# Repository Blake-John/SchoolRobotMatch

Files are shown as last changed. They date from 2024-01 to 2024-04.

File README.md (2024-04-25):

# RobotMatch

该仓库用于存放华工机器人校内赛的各种 **代码，文件，资料** 等其中，主要分为

* `ComputerVisioin` 
* `Microccontroller` 
* `MechanicalStructure` 

三个板块，其中

* `ComputerVision` 用于存放视觉识别的相关代码，模型等
* `Microcontroller` 用于存放电控的相关代码，电路板设计等资料
* `MechanicalStructure` 用于存放小车的结构，模型等

> 详细更新信息请阅读 [CHANGELOG](CHANGELOG.md)

## 1. ComputerVisioin

### 1.0 Structure

```
.
├── Modules                        # 一些模块
├── MidTermAssessment              # 中期考核程序
├── debugging                      # 存放用于赛前赛时调试用的程序
└── VisionSolutions                # 比赛瞄准项目
```

### 1.1 Modules

存放这一些准备比赛时使用的模块，较为杂

### 1.2 MidTermAssessment

用于提交 **中期考核** ，代码效果展示见 [Video](./ComputerVision/MidTermAssessment/medias/1.mkv)

详情可见 [MidTermAssessment](./ComputerVision/MidTermAssessment/README.md) 以及 [What to do](./ComputerVision/MidTermAssessment/TODO.md)

### 1.3 debugging

关于该目录可见 [debugging](./ComputerVision/debugging/README.md) 以及 [what to do](./ComputerVision/debugging/TODO.md)

### 1.4 VisionSolutions

视觉方面的项目目录，存放了用于比赛瞄准的程序，可见 [VisionSolutions](./ComputerVision/VisionSolutions/README.md) 以及 [What to do](./ComputerVision/VisionSolutions/TODO.md)

## 2. MicroController

### 2.0 Structure

```
.
├── MajorControl_Source            # 比赛小车控制项目
├── PID速度环控制
├── RemoteController_nRF20L01      # 控制手柄
├── SerialControl                  # 串口通信代码
├── SerialMCU
└── SerialPWM
```

### 2.1 SerialControl

串口通信模块，实现在 Linux 系统下，通过 C++ 程序与 STM32 通信

### 2.2 SerialMCU

接受信息模块，将接受到的特定数据包在OLED上显示

### 2.3 SerialPWM

接受信息，并控制舵机旋转

### 2.4 RemoteController_nRF20L01

控制手柄的pcb项目

### 2.5 MajorControl_Source

电控的 PCB 板源文件， `ZET6` 主控板源代码， `C8T6`从控板源代码以及遥控手柄控制源码。

实现了通过手柄上的 2.4G 模块向 `ZET6` 主控板发送信息，从而驱动小车，并实现比赛所需要的捡球，上高台，兑换等功能

详细信息可见 [MajorControl_Source-README](./MicroController/MajorControl_Source/README.md)

## 3. MechanicalStructure
### 3.1 零件

小车结构的零件，包括小车的 **基本框架** ，**麦轮结构**，**扫球装置**，**tt130电机**

### 3.2 装配体

小车结构的装配体，包括 **局部装配体** 以及 **整车装配体**

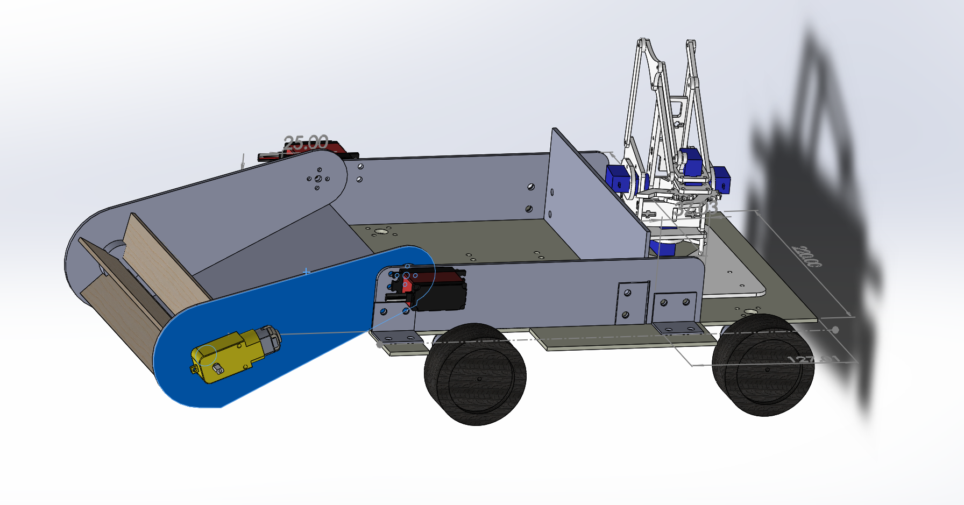
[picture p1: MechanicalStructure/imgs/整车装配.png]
Total


### 3.3 Mearm机械臂

机械臂的结构，包括各 **部位零件** 及 **装配体**

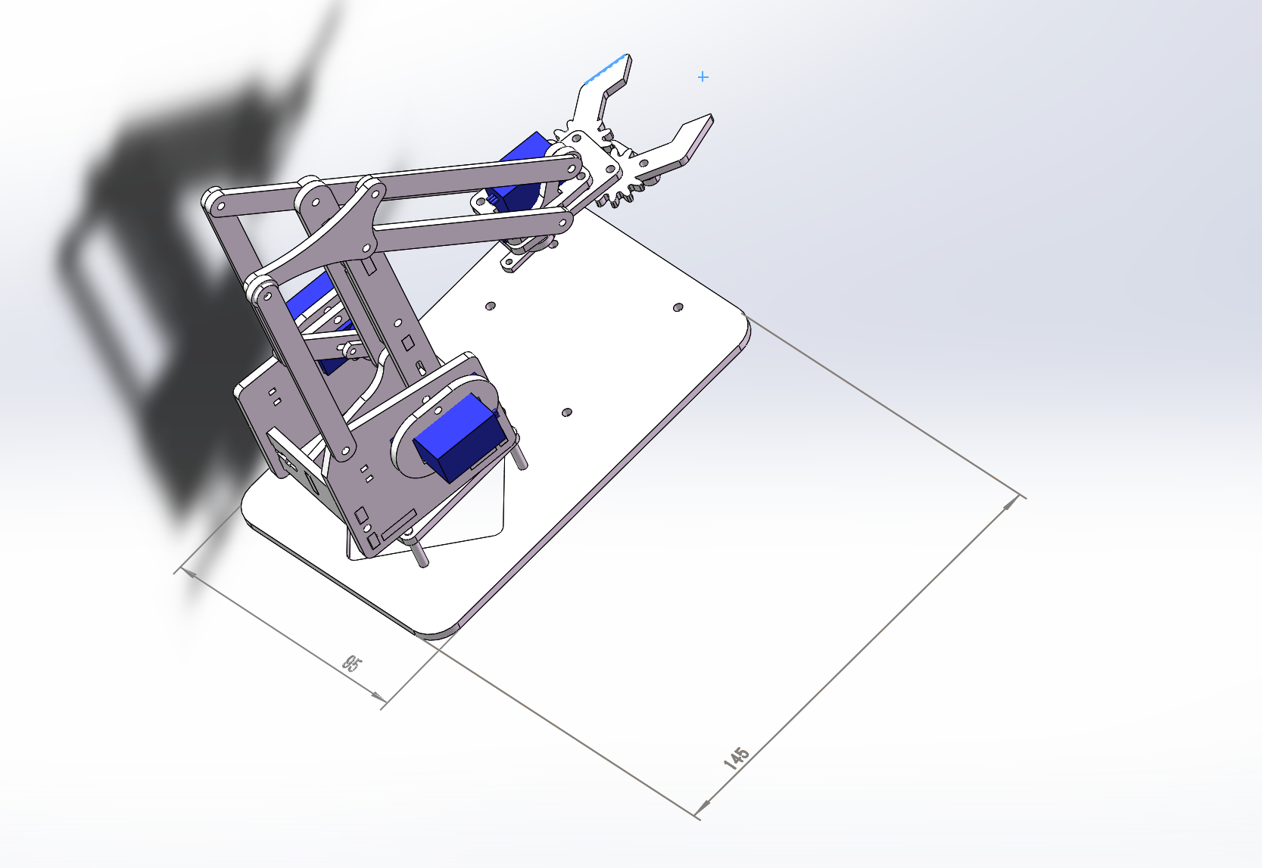
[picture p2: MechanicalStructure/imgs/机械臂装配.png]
Arm


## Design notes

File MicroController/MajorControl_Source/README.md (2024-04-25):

# 01 项目介绍

本项目是基于STM32F1系列的智能小车的操控与驱动代码，使用HAL库编写，IDE为CLion。可以实现平地小球收集，框内小球收集，上10±2cm高台等功能

# 02 使用芯片

* STM32F103C8T6 2片
* STM32F103ZET6 1片

# 03 目录结构

```
.
├── README.md
├── Regular.txt                     # 遥控器指令表/OLED菜单说明
├── PCB                             # 两张 PCB 源文件(嘉立创 EDA `.eprj`)
│   ├── MotherBoard.eprj              # 主控 PCB (还与另一张供电 PCB 相连)
│   └── RemoteController.eprj         # 遥控器 PCB
├── DriveControl                    # 电机、舵机驱动板(C8T6)源代码
├── RemoteController                # 遥控器源代码
└── RobotMatchZET6                  # 主控板源代码
```

# 04 功能说明

## 4.1 遥控器

1. 多级菜单，可以直接通过 **右摇杆** 与 **PCB上的按钮** 来操控、选择菜单，并且通过 `NRF24L01` 模块与主控板上的 `ZET6` 进行通信传输，同时会通过 **反色来显示当前所在行** 
2. 通过不同指令来指挥小车(指令表可以查看 [Regular](./Regular.md))，让小车处于不同状态
3. 在 `DMA` 模式下读取 `ADC` 数据，实现对摇杆状态的识别，并实现 **多级速度调节** 
4. PCB拥有 **充电、电源管理、降压升压** 功能

## 4.2 `ZET6` 主控板

1. 通过`NRF24L01` 来与遥控器通信，读取指令并使小车处于不同状态(上高台模式、滚筒实时控制模式、铲子控制模式、图像识别模式)
2. 通过 `TIM` 的编码器模式来 **读取电机编码器数据** ，实现 **电机测速与 `PID` 控制** 
3. 通过 `USART` 与小车驱动板(及另一块 `stm32f103c8t6` )通信，让小车驱动板输出不同的`PWM`，从而实现舵机的控制

## 4.3 C8T6小车驱动板

1. 通过 `USART` 与 `ZET6` 通信， **向 `ZET6` 发起数据申请** ，并等待数据回复，避免丢包或者数据串位的情况，让通信更加安全稳定
2. 对 `ZET6` 发过来的数据进行 **解析并进行相应操作** ，分为菜单状态操作与电机PWM操作
3. 在 `Detect` 模式下，解析电脑通过 `USB2TTL` 发送过来的数据，并对装有激光的舵机进行控制

# 05 使用说明

1. 通过嘉立创EDA软件打板得到遥控器与主控板，并对器件进行连接
2. 打开遥控器上的红色开关拨片，此时单片机上方两个LED应当全为红色，左边LED为通信 `Debug LED` ，当通信能被主控板正常接收时，为熄灭状态，右边为可编程LED
3. 让主控板接通电源，此时 `NRF24L01` 上电，并被初始化，正常情况下遥控器的通信 `Debug LED` 在此时熄灭
4. 推动遥控器 **左摇杆** ，可控制小车前进后退，向左向右平移，并且根据推动程度，改变小车的目标速度，通过 `PID` 使得小车有不同速度
5. 于 **0级菜单或者非控制状态** 下， **上下** 推动 **右摇杆** ，为 **选择菜单** ，0级菜单有四个模块，根据英文提示可以得知相应功能
6. 于 ** 0级菜单或者非控制状态** 下， **左右** 推动右摇杆，为控制小车 **顺逆时针原地旋转** 
7. 在 **滚筒实时控制模式** 状态下，右摇杆上下控制菜单的功能被 **锁定** ，改为 **滚筒的升起和下降** ，左右控制仍为顺逆时针旋转
8. 在 **上高台模式** 下，右摇杆被锁定， **上下控制滚筒升降** ，**左右控制小车后两根支撑柱升降** 
9. 在 **`Boost` 模式** 下，驱动板会 **忽略 `PID`** ，强制输出较高PWM，让小车具有较强的启动力
10. 在 **`Detect` 模式** 下，`ZET6` 的 **`USART` 会失能** ，同时 **小车驱动板(C8T6)的 `USART` 与电脑连接**，接受并解析电脑发送的两个舵机 `PWM` 控制数据， **直到 `Detect` 模式的退出** ， `ZET6` 的 `USART` 重新使能，并向驱动板发送一个 `\t` 来激活驱动板发送请求的行为
11. 在 **铲子控制模式** 下，**右摇杆被锁定** ，上下控制铲子旋转角度，左右控制齿条伸出收入行为
12. **在任何模式下强制退出1级菜单都会使小车清空状态，滚筒，传送带，支撑住，铲子都会回到初始位置**

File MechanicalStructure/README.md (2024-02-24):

# 注释说明
### 1. 为避免螺丝对木板造成干涉，tt130电机的固定采用热熔胶固定，如下图。

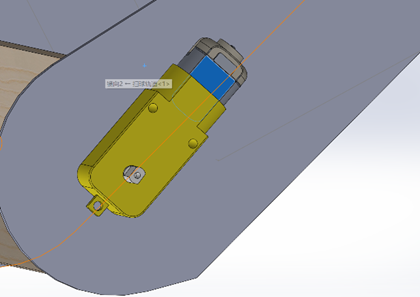
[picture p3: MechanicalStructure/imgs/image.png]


### 2. 此处给轴承预留孔位，轴承外径8mm,内径4mm,厚度3mm。如下图

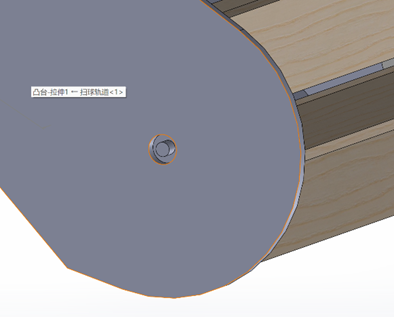
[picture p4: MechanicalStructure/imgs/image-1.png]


### 3. 储球区域后续将增加一层斜板，可避免螺丝对小球滚动的干扰



### 4. 小车底部预留舵机支架，用于控制撑杆将车撑上台阶（与范例同理），但杆的长度，触地范围等还需后期实车组装后调试得出，因此中期考核不呈现撑杆模型

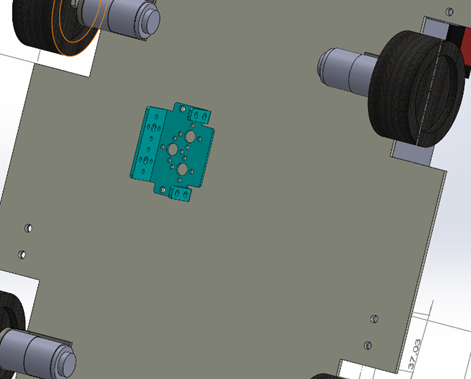
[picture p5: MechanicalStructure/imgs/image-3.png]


## 整车装配



## 机械臂装配



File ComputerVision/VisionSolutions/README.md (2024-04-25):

# 01 简介

本项目是基于 `OpenCV` 和 `C++` 小车视觉识别程序，主要包含3种 `Solution` 。

# 02 开发环境

* System - Arch / Ubuntu
* Language - C++ / Python
* Libararies - OpenCV-4.9.0
* 杰锐微通相机 -  DF100 720P 2.8mm

# 03 目录结构

```
.
├── README.md
├── Solution1          # 基于 Yolo 的静态瞄准
├── Solution2          # 基于 Yolo 的动态瞄准
├── Solution3          # 基于传统视觉的瞄准
├── test.py
└── TODO.md
```

# 04 功能说明

## 4.1 目标检测

1. `Solution1` 和 `Solution2` 通过 `dnn` 模块加载 `Yolo to ONNX` 模型，并通过推理来获取目标的位置信息
2. `Solution3` 通过传统的视觉方法来检测并获取目标的位置信息

## 4.2 通信

三个解决方案皆通过操控 `Linux` 系统下 `ttyUSB0` 文件来操控串口的行为。电脑通过 `usb2ttl` 模块和单片机相连，并又程序向串口文件中写入数据，从而实现数据的传输。

## 4.3 瞄准

1. `Solution1` 通过计算激光位置与目标位置之间的偏角，一次性获取激光偏转的角度
2. `Solution2` 和 `Solution3` 通过实时获取激光的位置，并通过动态调整偏转的角度，从而实现动态瞄准

# 05 使用

三个方案均在 `Linux` 系统下通过 `C++` 开发，需要通过 `cmake` 和 `make` 来编译程序

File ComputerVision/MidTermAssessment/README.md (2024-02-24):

# 视觉中期考核

此次完成的是视觉组的中期考核

* 题目一、三、四的展示视频见 [Video1](medias/1.mkv)
* 题目二没有专门录制，但是可以见 [Video2](medias/2.mp4) 以及 [Demonstration](medias/0.jpg)

所有代码都上传至 [仓库](https://gitee.com/blake-john/robot-match/tree/master/ComputerVision/MidTermAssessment) 中，可以通过以下命令查看

```bash
git clone https://gitee.com/blake-john/robot-match.git
```

## 01 基本说明

这次中期考核的代码由两个基本模块 `mathfunc` 和 `yolo` 组成。项目中

* `mathfunc` 是用于 **bbox排序**、 **计算偏角** 的模块
* `yolo` 适用于调用网络模型进行 **推理** 的模块
* `model/` 存放用于推理的 **onnx 模型**
* `videos/` 存放 **展示视频**
* `imgs/` 存放 **测试用的图片**

## 02  `mathfunc` 

该模块用于存放基本 **数学方法** 以及 **与相机有关的宏定义**、

### `YawPitch` 

使用最基本的 **几何方法** 计算欧拉角中的 **`Yaw` 偏航角** 以及 **`Pitch` 俯仰角**。

我看到群里有人使用 `PnP` 来计算坐标，但是在实际比赛的时候，难以确定已知的点用于解算，或者说误差应该不小，还有最最重要的是 **我不会！！！QwQ T-T :(**

### `order`

通过 $x, y$ 坐标 选出上方的五个标准区色块

## 03 `yolo`

使用 `yolov3` 的 `yolov3-tiny.pt` 预训练模型进行训练，然后导出为 `onnx` 模型，利用opencv中的 `dnn` 模块加载模型并进行推理

对于该模块，我将网络的初始化及推理 **封装成一个 `Yolo` 类** ，并通过接收 **模型所在路径** 作为参数来初始化该类。接着在类中定义了推理的方法，但是为了 **减少资源的开销**，我将推理过程全都写在 `Detect` 方法中，大致思路为：**设置输入**，**前向推理**，**通过置信度过滤bbox**，**使用NMS获取最终目标的bbox**。

至于为什么不用传统的 **边缘检测以及HSV色域**，是因为我我手搓的那块板太烂了，而且在家里拍出来的照片背景一堆，再加上不知到时候比赛现场的环境怎么样，于是就选了用神经网络来识别。

> 代码的讲解可见 **代码本身的注释**，或者仓库中的 [CHANGELOG.md](https://gitee.com/blake-john/robot-match/blob/master/CHANGELOG.md)

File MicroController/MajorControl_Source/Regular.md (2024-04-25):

# OLED Menu：

## 0级菜单

```
第一行 : 滚轮控制					->	1级菜单(A)

第二行 : 传送带控制  				->	1级菜单(B)

第三行 : 齿条，铲子  				->	1级菜单(C)

第四行 : 图像识别模式 & 高台模式	->	1级菜单(D)
```

## 1级菜单(A)

```
第一行 : 启动，停止	
第二行 : 实时控制滚筒	
```

## 1级菜单(B)

```
第一行 : 启动，停止	
第二行 : 去折叠		
第三行 : 折叠			
```

## 1级菜单(C)

```
第一行 : 自动化执行一次	
第二行 : 进入手动模式		
第三行 : 显示是否为手动模式(若是手动模式，则右摇杆会被锁定无法控制菜单)
```

## 1级菜单(D)

```
第一行 : 激光开启，关闭						5.1
第二行 : 进入，退出图像识别Slave模式		5.2
```

# 初始状态

以下是一些代码中宏定义的记录 : 

对于第一次 : unsign char 的结构：`abcd efgh`

其中，`a, b, c, d, e, f` 表示 **操作对象**， `g, h` 表示 **操作**

```
滚筒启停			{0000 01xx}		启动{01}		停止{00}			
传送带启停			{0000 11xx}		启动{01}		停止{00}			
传送带折展			{0001 00xx}		展开{01}		折叠{00}
//铲子自动执行		{0001 01xx}		执行{01}
//铲子切换手自		{0001 10xx}		自动{01}		手动{00}
摄像机打开激光		{0001 11xx}		打开{01}		关闭{00}			
识别模式			{0010 00xx}		进入{01}		退出{00]
铲子控制			{0010 01xx}		升高{01}		降低{00}
滚筒控制			{0100 00xx}		升高{01}		降低{00}
支撑柱控制			{0100 01xx}		升高{01}		降低{00}
平台模式			{0010 11xx}		进入{01}		退出{00]
滚筒升高			{0011 00xx}		升高{01}		降低{00}
扔球滚筒控制		{0011 01xx}		进入{01}		退出{00}
Boost Mode			{0011 10xx}		进入{01}		退出{00}
```

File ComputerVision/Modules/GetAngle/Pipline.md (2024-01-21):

# Get the Angle to Aim the Target

## 1. find the target

We will transform the `AutoAimming` module into a lib to get the targets and their position informations.

But before we apply the module to this project, we will first attempt the function **detecting the single target and calculate the angle** .

## 2. get the distance

If we want to get the angle, we must know how far does the target away from the camera. So we will also transform the `GetDistance` module into a lib.

## 3. get the angle

We will write a new module to get the angle **based on the position informations and the distance** 

# Pipline

1. transfrom the module `AutoAimming` and `GetDistance` , integrate and seperate them into the small module
2. test it on the single target
3. write the module to get the angle
4. apply all the module **on the img**
5. detect **webcam on real time**

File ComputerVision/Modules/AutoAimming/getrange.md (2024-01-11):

要得到纯色图片的颜色阈值，可以使用以下步骤：

1. 读取纯色图片。你可以使用 OpenCV 的 `imread()` 函数来加载图片。

```python
import cv2

# 读取纯色图片
image = cv2.imread('solid_color.jpg')
```

2. 将图片转换为 HSV 颜色空间。HSV 颜色空间更适合处理颜色信息，因为它可以将亮度（Value）和饱和度（Saturation）与颜色（Hue）分开。

```python
# 转换为 HSV 颜色空间
hsv_image = cv2.cvtColor(image, cv2.COLOR_BGR2HSV)
```

3. 计算颜色的平均值。遍历图像的所有像素，并计算像素值的平均值。

```python
# 计算颜色的平均值
average_color = hsv_image.mean(axis=0).mean(axis=0)
```

4. 根据平均颜色创建阈值范围。你可以根据需要调整阈值范围的大小。

```python
# 创建颜色阈值范围
threshold = 20  # 阈值范围大小
lower_color = (average_color[0] - threshold, average_color[1] - threshold, average_color[2] - threshold)
upper_color = (average_color[0] + threshold, average_color[1] + threshold, average_color[2] + threshold)
```

5. 应用颜色阈值，提取纯色区域。

```python
# 创建掩膜，根据颜色阈值将图像分割为黑白二值图像
mask = cv2.inRange(hsv_image, lower_color, upper_color)

# 应用掩膜到原始图像
result = cv2.bitwise_and(image, image, mask=mask)
```

最后，你可以通过 `imshow()` 函数显示原始图像和提取的纯色区域。

请注意，这些步骤是基于假设输入图片是纯色的。如果图片中有噪点或变化较大的颜色，则可能需要进行一些额外的处理步骤来提取出所需的颜色。

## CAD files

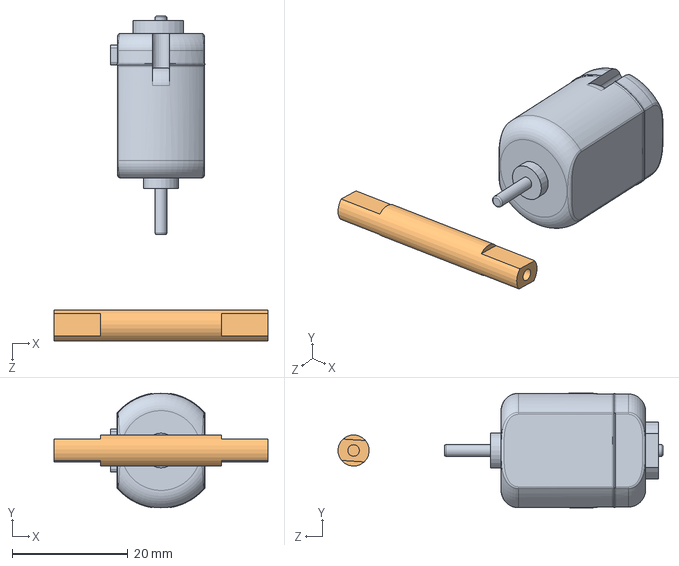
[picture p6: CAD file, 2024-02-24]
MechanicalStructure/装配体/DC Motor Gearbox.SLDASM
37.0 x 19.8 x 56.2 mm
output shaft
motor

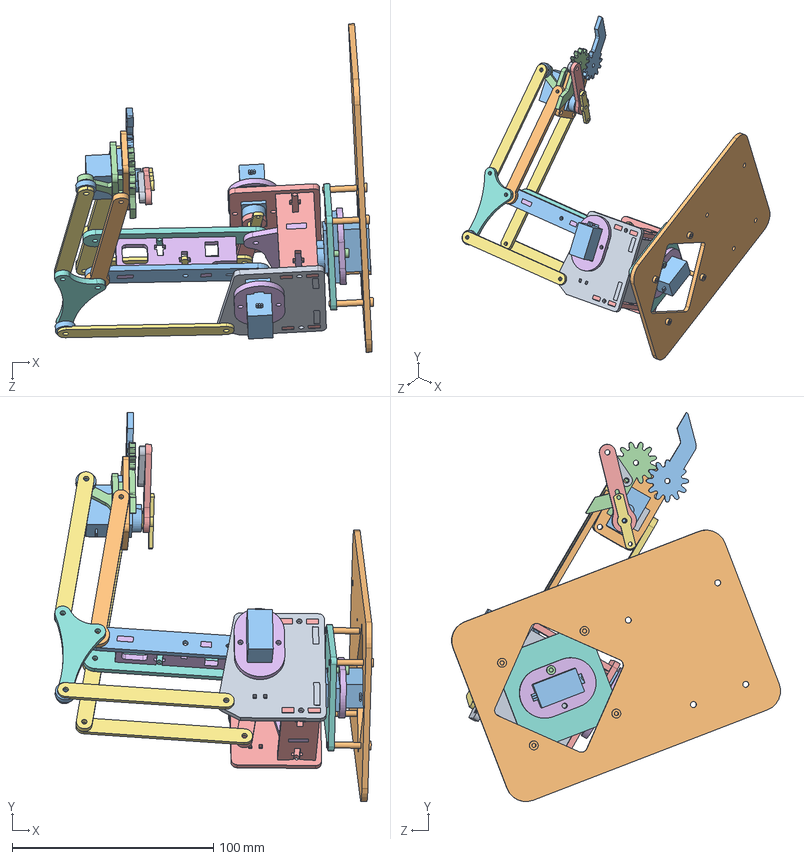
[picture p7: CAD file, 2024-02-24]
MechanicalStructure/Mearm机械臂/机械臂.SLDASM
158.7 x 193.3 x 163.4 mm
次级底板
底板
垫片 x 2
舵机鞍座(上)
舵机舵片-单侧-长 x 2
舵机限位器 x 3
连杆 x 3
枢轴夹板
右臂舵机夹板
右臂关节
右臂基部关节
右臂连接件
左臂舵机夹板
左臂根部
左臂关节
左臂基部关节
左臂连接件
M3×20内六角螺钉 x 4
舵机-SG90 x 4
M3×8内六角螺钉
臂间支撑架-基部 x 2
臂间支撑架-上部
舵机舵片-双侧等长 x 3
连杆(异型)
夹爪驱动杆
舵机鞍座(下)
夹爪
左夹

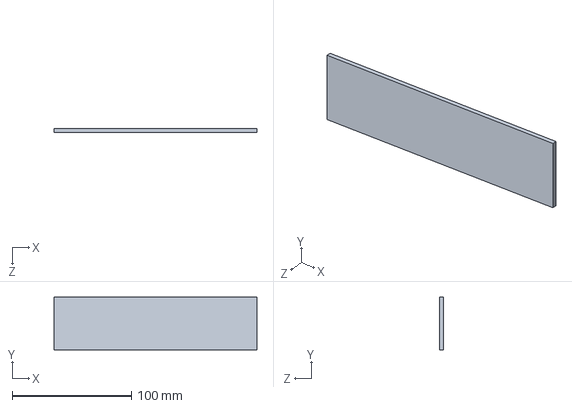
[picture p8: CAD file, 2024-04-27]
MechanicalStructure/小车结构/cth/传送带4.SLDPRT
170.0 x 44.0 x 3.00 mm

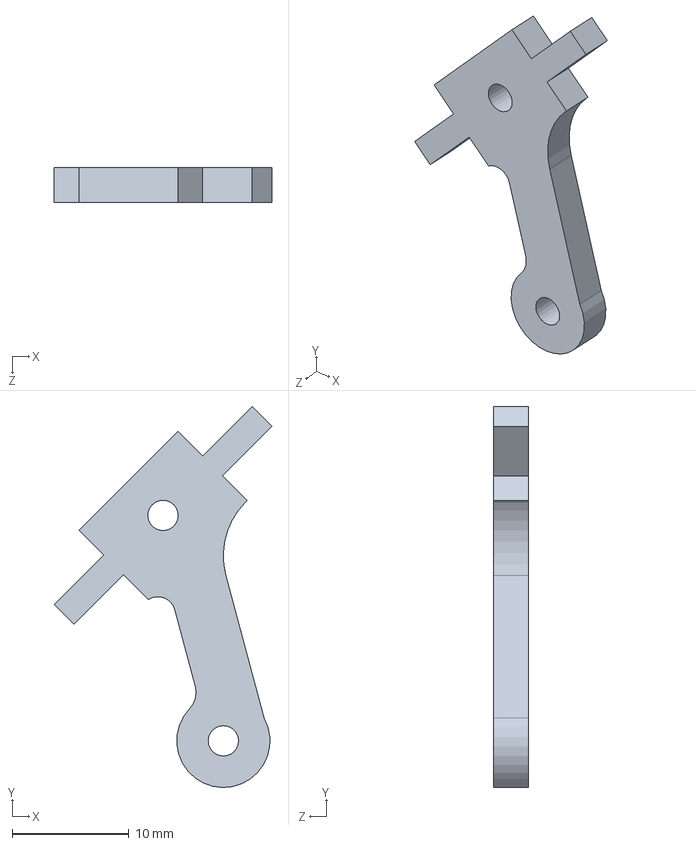
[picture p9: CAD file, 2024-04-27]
MechanicalStructure/小车结构/Mearm/右臂连接件.SLDPRT
18.7 x 32.7 x 3.00 mm

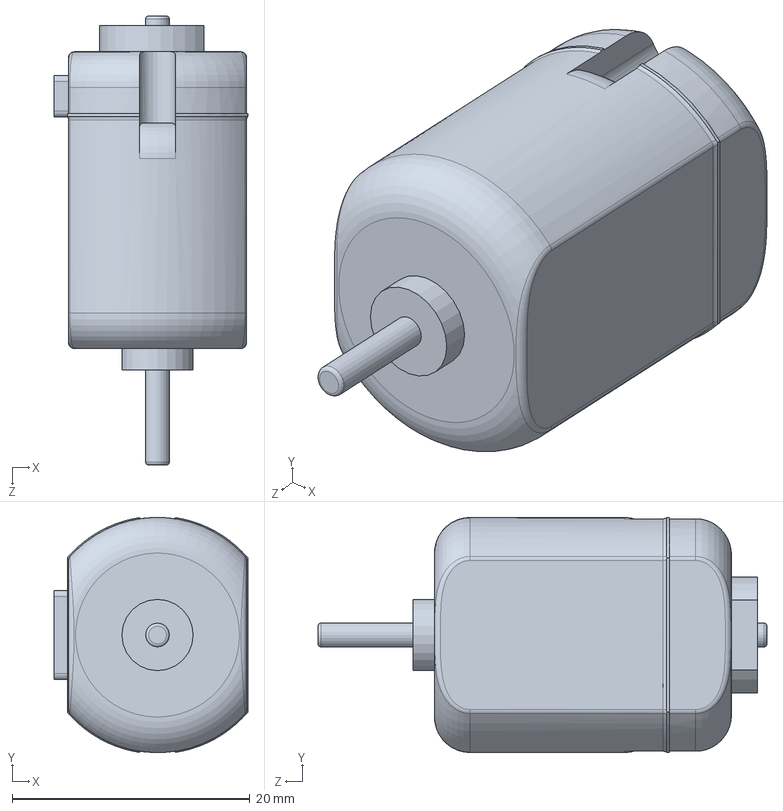
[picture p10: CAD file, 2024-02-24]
MechanicalStructure/小车结构/tt130电机/motor.SLDPRT
16.3 x 19.8 x 37.8 mm

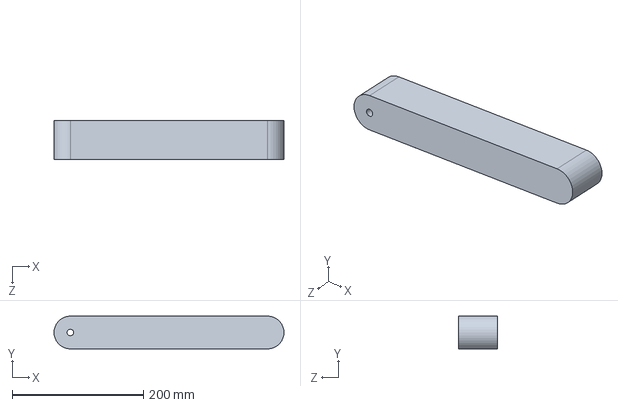
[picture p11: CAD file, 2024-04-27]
MechanicalStructure/小车结构/传送带模拟.SLDPRT
350.0 x 50.0 x 60.0 mm

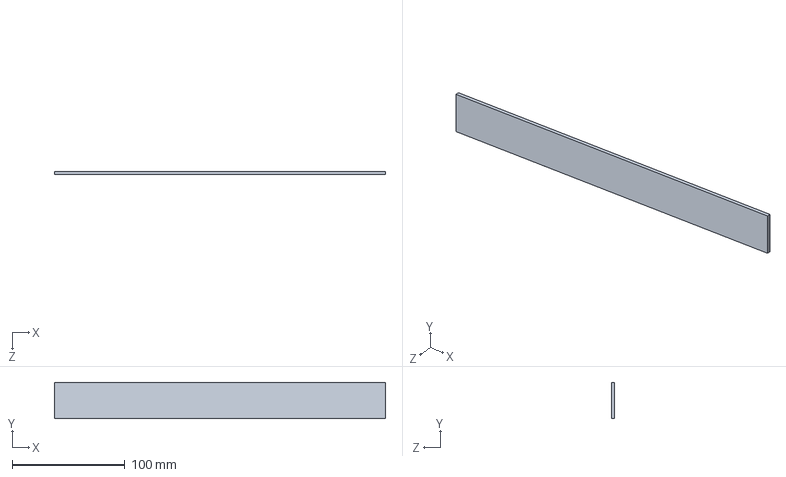
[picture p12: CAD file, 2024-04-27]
MechanicalStructure/小车结构/扫球装置/扫球木板.SLDPRT
294.0 x 32.0 x 3.00 mm

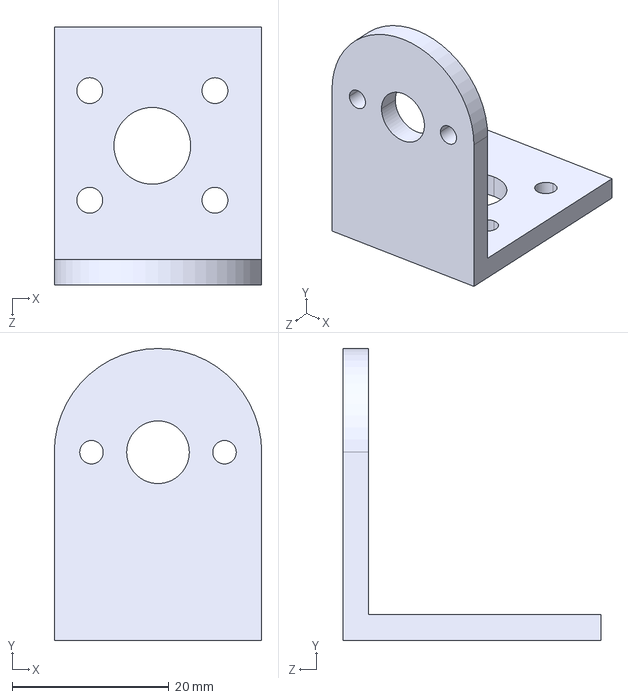
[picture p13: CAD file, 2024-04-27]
MechanicalStructure/小车结构/麦轮整体/25金属电机支架.STEP
26.5 x 37.3 x 33.0 mm

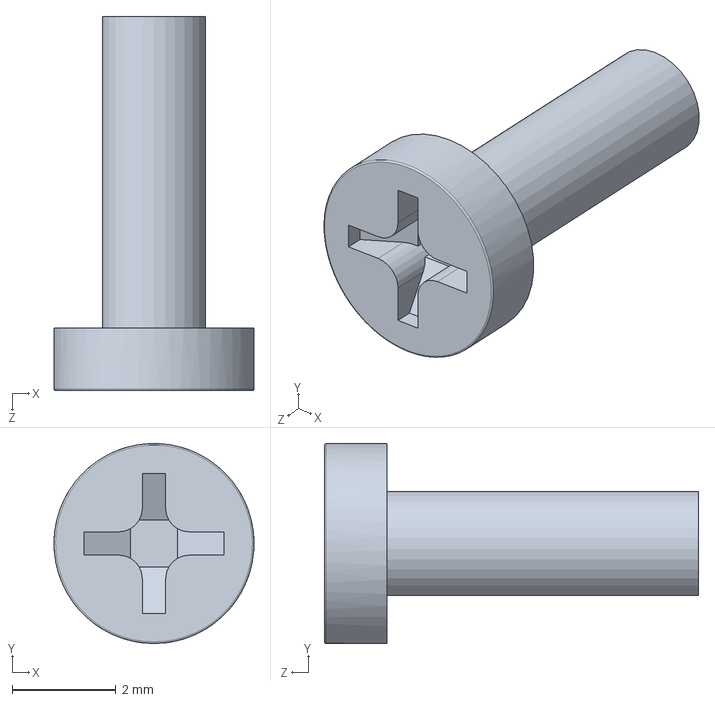
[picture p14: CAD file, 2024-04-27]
MechanicalStructure/小车结构/Mearm/M2×6十字螺钉.SLDPRT
3.85 x 3.85 x 7.20 mm

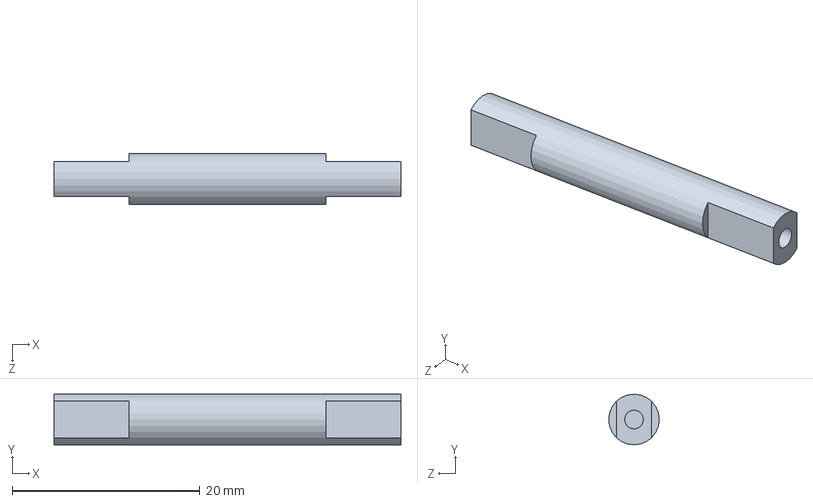
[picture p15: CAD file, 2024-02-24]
MechanicalStructure/小车结构/tt130电机/output shaft.SLDPRT
37.0 x 5.40 x 5.40 mm

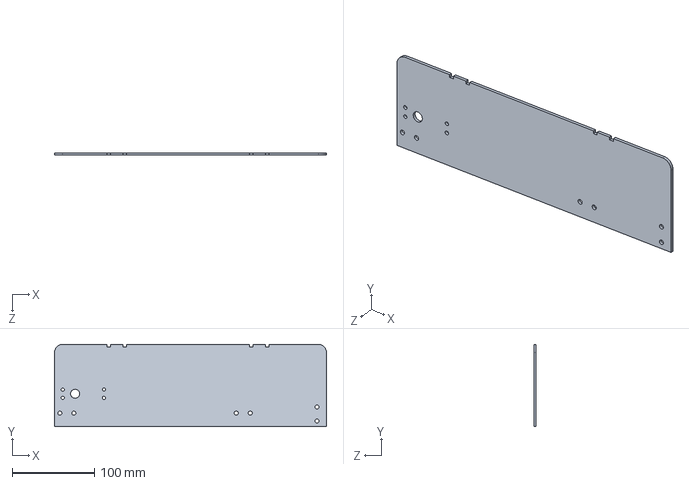
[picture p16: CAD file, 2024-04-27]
MechanicalStructure/小车结构/侧板.SLDPRT
330.0 x 100.0 x 3.00 mm

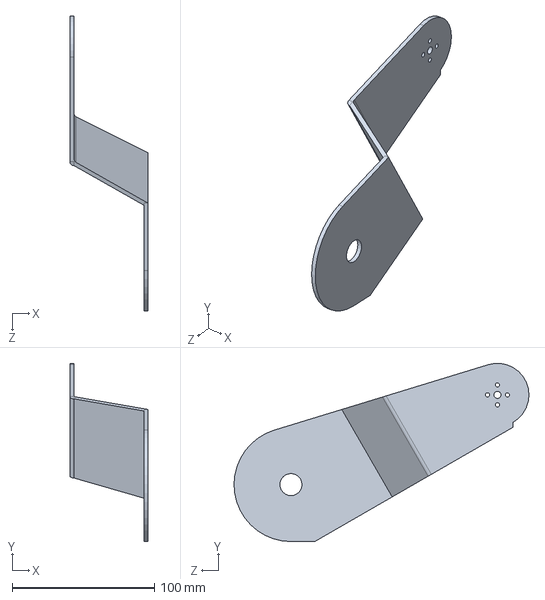
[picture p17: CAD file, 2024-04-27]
MechanicalStructure/小车结构/扫球装置/扫球轨道右侧挡板.SLDPRT
55.0 x 125.1 x 207.2 mm

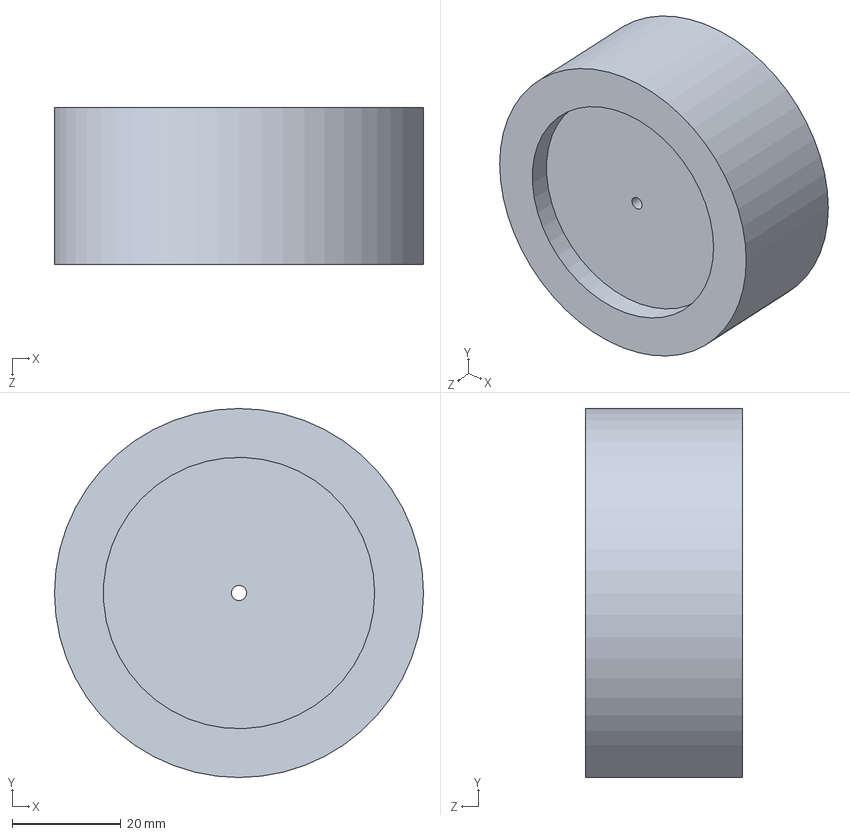
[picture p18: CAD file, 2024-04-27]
MechanicalStructure/小车结构/麦轮整体/麦轮.SLDPRT
68.0 x 68.0 x 29.0 mm

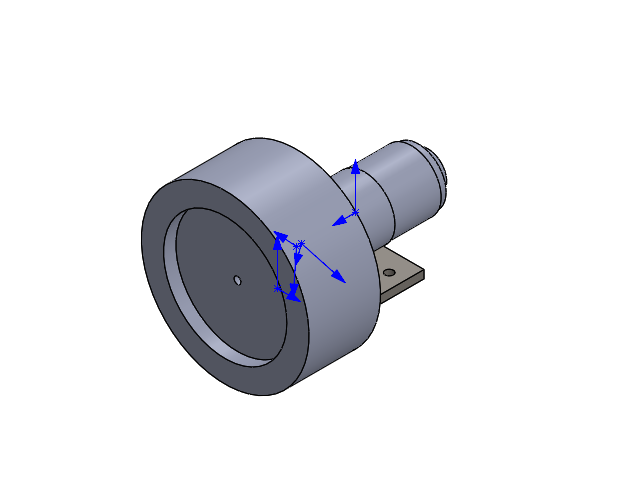
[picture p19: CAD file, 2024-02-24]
MechanicalStructure/装配体/麦轮加电机装配体.SLDASM
25金属电机支架
六角联轴器
编码电机
麦轮

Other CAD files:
MechanicalStructure/小车结构/cth/铲.SLDASM
MechanicalStructure/装配体/整车装配.SLDASM
MechanicalStructure/小车结构/cth/传送带.SLDASM
MechanicalStructure/小车结构/整车装配2.SLDASM
MechanicalStructure/Mearm机械臂/右臂关节.SLDPRT
MechanicalStructure/Mearm机械臂/右臂基部关节.SLDPRT
MechanicalStructure/Mearm机械臂/右臂舵机夹板.SLDPRT
MechanicalStructure/Mearm机械臂/右臂连接件.SLDPRT
MechanicalStructure/Mearm机械臂/垫片.SLDPRT
MechanicalStructure/Mearm机械臂/夹爪.SLDPRT
MechanicalStructure/Mearm机械臂/夹爪驱动杆.SLDPRT
MechanicalStructure/Mearm机械臂/左夹.SLDPRT
MechanicalStructure/Mearm机械臂/左臂关节.SLDPRT
MechanicalStructure/Mearm机械臂/左臂基部关节.SLDPRT
MechanicalStructure/Mearm机械臂/左臂根部.SLDPRT
MechanicalStructure/Mearm机械臂/左臂舵机夹板.SLDPRT
MechanicalStructure/Mearm机械臂/左臂连接件.SLDPRT
MechanicalStructure/Mearm机械臂/底板.SLDPRT
MechanicalStructure/Mearm机械臂/枢轴夹板.SLDPRT
MechanicalStructure/Mearm机械臂/舵机-SG90.SLDPRT
MechanicalStructure/Mearm机械臂/舵机舵片-单侧-长.SLDPRT
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

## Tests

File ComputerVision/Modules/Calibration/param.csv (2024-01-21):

u = 3e-06
focus = 0.0028
d_list = [0.0031405032467532465, 0.003179707792207792, 0.0031884090909090907, 0.0032028571428571427, 0.003216038961038961, 0.003204058441558442, 0.0032028571428571427, 0.003202597402597402, 0.003190275974025974, 0.0032174512987012986]
d_average = 0.003194475649350649, 0.0031945
w * h = 1280 * 720

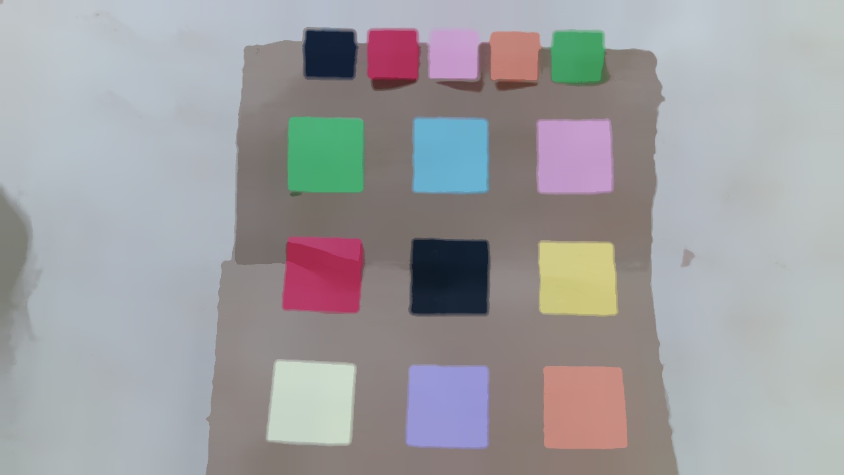
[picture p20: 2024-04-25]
ComputerVision/debugging/AutoAimming/imgs/testimg.jpg

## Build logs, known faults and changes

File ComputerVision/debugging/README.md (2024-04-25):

# debugging

该目录下的程序主要用于实现比赛前的调试以及比赛期间的调试

```
.
├── README.md
├── TODO.md
├── AutoAimming
├── bright_Test
├── ColorPicker
├── ColorRange.txt
├── laseraim
├── data640                  # 收集的数据集
├── filtering                # 用于测试图像处理的效果
├── shootdatasets            # 用于收集数据集
└── videocapture             # 用于录制视频
```

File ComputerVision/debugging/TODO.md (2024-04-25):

# the pipeline to debug the visual solution

1. collect the color range of the img in HSV
2. collect the dataset for yolo
3. try the smooth and filter
4. collect the color range of the laser

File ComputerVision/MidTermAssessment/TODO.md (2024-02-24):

# Something to do before 2-20 19:00

## 01 rewrite the Angle Calculate Module

the old one has a fatal error in math, since I had mixed the math concept of the angle.

- [x] rewrite the module by Cosine Theorem

## 02 write the project for MidTermAssessment

the project should show all the tasks

- [x] Project : MidTermAssessment

## 03 write the module to get the Euler Angle

this should calculate the euler angle from the center to the target

- [x] yaw pitch

## 04 write the Illustration Document

for the assessment

- [x] docs

## 05 record the video

for the assessment

- [x] video

> optional : 
> Use the traditional cv method such as get the HSV Range before to detect the color pieces
> - [] traditional way

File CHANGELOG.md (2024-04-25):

## 2024-04-25
### 1. FEATURE 新增

1. 电控的项目源代码
2. 视觉的项目源代码

### 2. CHANGE 变更

更新了根目录下 `README.md` 文件的结构

### 3. FIXED 修复

None

### 4. ILLUSTRATION 说明

1. 电控的项目通过 `CLion` 开发
2. 视觉的项目通过 `Linux` 开发

---

## 2024-02-20
### 1. FEATURE 新增
#### MidTermAssessment

新增模块用于中期考核提交，包括展示视频，代码，模型等

### 2. CHANGE 变更
无

### 3. FIXED 修复
无

### 4. ILLUSTRATION 说明

1. 用于计算偏角的方法与之前 `V2` 以及 `GetAngle` 的方法不同，之前的方法有错的地方，这次的方法更加合理

---

## 2024-02-19
### 1. FEATURE 新增
无
### 2. CHANGE 变更
#### `MechanicalStructure`

新增各种零件，小车底盘部分基本完成

### 3. FIXED 修复
无

### 4. ILLUSTRATION 说明

机械部分说明请看“注释说明”文件

---

## 2024-02-12 15:30
### 1. FEATURE 新增
无
### 2. CHANGE 变更
#### `V2`

此次在 `V2` 中新增大量神经网络训练模型，并且新增了通过模型预测得到的结果来 **按顺序标注** 并 **计算偏转角度** 的功能。

### 3. FIXED 修复
无

### 4. ILLUSTRATION 说明

1. 这次增加了不少通过yolo训练出来的模型，但是识别的效果还是不够满意。或许是从 `pt` 模型转化成 `onnx` 模型还是有所损失。

2. 由于上面说的识别效果仍待加强，因此此次的程序中其实存在一些让人不太满意的地方，不过用于中期考核因该是没有问题的。

---

## 2024-02-08 23: 20
### 1. FEATURE 新增
#### `ColorPicker` :

C++ 程序，通过获取HSV色域。

#### `V1` :

C++ 程序，本来打算通过 onnx 模型将相机中的所有色块检测出来，然后通过获取检测出来的色块 HSV 阈值来进一步精确的检测色块，但是发现拍出来的照片效果不好，阈值相差太大，无法通过同一的阈值来限定，遂放弃。

#### `V2` : 

C++ 程序，通过 onnx 来获取所有色块及其标签，打算通过模型判断出来的标签来获得检测顺序，但是还没有写完。

### 2. CHANGE 变更
无

### 3. FIXED 修复
无

### 4. ILLUSTRATION 说明

1. 此次使用的 onnx 模型是在 `yolov3-tiny.pt` 预训练模型的基础上训练得到的模型，因此会更加轻量，同时检测效果也几乎相近。

2. `V2` 的程序其实和之前 `Aim` 的程序可以说是相近的，但是目前仍在开发中，打算纯粹通过神经网络来进行瞄准。

---

## 2024-02-06
### 1. FEATURE 新增
#### MachineStructure : 

小车底盘部分：六角联轴器，角码

### 2. CHANGE 变更
无

### 3. FIXED 修复
无

### 4. ILLUSTRATION 说明
未完成，谨慎食用

---

## 2024-02-05 10: 30
### 1. FEATURE 新增
#### `Aim` :

C++ 程序，通过yolov5实现了色块的获取。

### 2. CHANGE 变更
无

### 3. FIXED 修复
无

### 4. ILLUSTRATION 说明

1. `Aim` 程序在 Windows 系统下开发，在 yolov5n 预训练模型上对自己做的数据集训练 1000 轮后得到的模型转为 onnx ，然后利用 OpenCV 的 `DNN` 模块加载该模型并进行推理，获得了能够识别这次比赛中的色块的程序。

2. 但是这次的模型较为庞大，导致实时识别的视频帧率 **不高** ，但是对这次比赛来说够了。不过后续应该重新训练出更轻量的模型，或者将此次训练出来的模型进行量化，或者使用 yolov3，v4 等网络结构来减轻模型的重量。

---

## 2024-01-25 12：05
### 1. FEATURE 新增
#### `SerialControl` :

C++ 程序，实现 Linnux 通过程序与STM32串口进行通信。

#### `SerialMCU` :

C 程序，基于 STM32F103C8T6 芯片开发，实现了在OLED屏幕显示串口传来的具有特定包头包尾的数据包。

#### `SerialPWM` :

C 程序，基于 STM32F103C8T6 芯片开发，实现了根据上位机通过串口传来的数据包来控制舵机旋转，并将此次旋转角度显示在OLED屏幕上。

### 2. CHANGE 变更
无

### 3. FIXED 修复
无

### 4. ILLUSTRATION 说明

1. `SerialControl` 模块在 Linux 系统下开发，通过 CMake 编译，编译后的可执行文件存放于 `build/` 目录下。由于该模块为 **单文件** 模块，~~因此理论上可以直接在 Windows 系统上通过 VSCode 生成可执行文件并运行，但是还没有试过~~。
> 更正：由于使用的是ubuntu的串口，因此Windows下并没有直接的串口相对于，无法直接运行

2. `SerialMCU` 和 `SerialPWM` **不是通过 Keil5 来开发！！！** 而是 **通过 `Embedded IDE` 在 VSCode 上开发** ，并且通过 `openocd` 进行烧录。但是可以在 VSCode 中导出为 Keil5项目。

---

## 2024-01-21 21：45
### 1. FEATURE 新增
#### Calibration : 

Python 和 C++ 混合模块，包括 `shoot` 和 `calibrate`

##### `shoot` 

拍摄并存储用于测量相距的图片

##### `calibrate`

该模块成功根据 **目标的长宽** 以及 **目标离相机镜头的距离** 计算获得 **摄像头的相距** ，并将一些摄像头的内参写入 `param.csv` 文件中，包括：
1. 像元尺寸 `u` 
2. 焦距 `focus`
3. 不同图片计算得到的相距列表 `d_list`
4. 根据列表计算得到的平均相距 `d_avg`
5. 相机使用的分辨率 `w * h` 

### 2. CHANGE 变更
#### GetDistance

更改内部参数，将计算中使用的 **焦距** 改为测得的 **相距**

根据测得的相距来计算距离和偏角，精确度比原本搞了一档，结果如下：

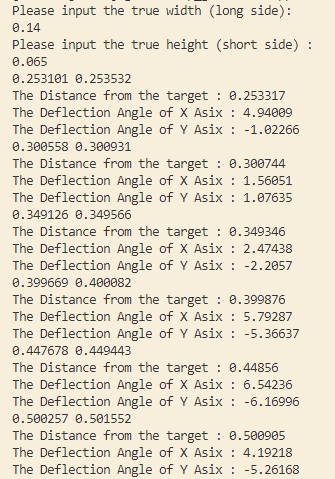
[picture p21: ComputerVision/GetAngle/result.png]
测距和算偏角结果


此次测量依次在距离为 0.25m, 0.3m, 0.35m, 0.4m, 0.45m, 0.5m 下进行，可以看到精度已经有所提高，误差控制在 0.5cm 以内

### 3. FIXED 修复
无

### 4. ILLUSTRATION 说明

`Calibration` 在 **Windows** 系统下编写，其中 `shoot` 由 C++ 编写并利用 `CMake` 进行编译，编译后的可执行文件存放于 `build/shoot.exe` ; `calibrate` 由 Python 编写

此次测量的相距为 `杰锐微通 DF-100 2.8mm 90度` 摄像头的相距

在此次试验中，得到的偏角似乎更加精确了，但是并没有实际使用过，接下来应该先将 **串口通信** 解决，然后改用 `PNP` 算法进行 **测距** 和 **算偏角** 

而且到目前为止的工作都是对 **背景干扰少(甚至可以说无背景干扰)** 和 **单个目标** 进行的，需要扩大到比赛时的多目标 

---

## 2024-01-21 16：30
### 1. FEATURE 新增
#### GetAngle : 

C++ 程序，成功根据 **目标** 的长宽以及 **相机的参数** 以及 **目标离相机的大致距离** 获得目标中心离画面中心的 **偏角**。

经过测试，这个偏角貌似挺合理？但是因为没有相应的器件把相机装到舵机上，所以是手动比划，看上去还可以。

该模块合并了前两个模块 `GetDistance` 和 `AutoAimming` 中的函数，具有两个可执行程序，其中：
1. `main` 是单张图片的偏角计算
2. `main2` 用于摄像头按需计算目标偏角，按下 `0` 可以计算按下时离镜头中心的偏角

### 2. CHANGE 变更
#### AutoAimming

修改了一些注释样式

#### GetDistance

修改了一些注释样式

### 3. FIXED 修复
无

### 4. ILLUSTRATION 说明
`GetAngle` 在 **Linux** 系统下编写，并利用 `CMake` 进行编译，编译后的可执行文件存放于 `build/main` 

此次 `GetAngle` 模块由 `杰锐微通 DF-100 2.8mm 90度` 摄像头来完成

此外，今天测试偏角的时候发现测距的函数有偏差，不能忍的偏差，主要原因是对原理的认知有一点点偏差，实际上利用相似的原理测距需要的是 **相距** 而不是 **焦距** ，因此接下来需要标定相机的 **相距**

而且到目前为止的工作都是对 **背景干扰少(甚至可以说无背景干扰)** 和 **单个目标** 进行的，需要扩大到比赛时的多目标 

---

## 2024-01-18
### 1. FEATURE 新增
#### GetDistance : 

C++ 程序，成功根据 **目标** 的长宽以及 **相机的参数** 获得 **目标里相机的大致距离** 

经过 **三次不严谨的测试** ， 该测量准确度 **还行** ， 误差控制在 **3cm/10%** 以内，且此次测试由于距离较短(30cm以内)，误差显得更为突出，预估测量50cm以上的距离效果可能好一点？

同时，在该模块下还有一个用于获取实验数据的 `shoot` 工具，和用于颜色获取的 `pick` 工具(尚未完成)

### 2. CHANGE 变更
#### AutoAimming

新增了 `mathfunc` 模块用于计算偏角，但是目前只有实现获取 **目标中心在相机中的坐标** 的 `getCenter` 这一函数

另外，修改了 `process` 模块中的头文件，使得函数原型更为完整

### 3. FIXED 修复
无

### 4. ILLUSTRATION 说明
`GetDistance` 在 **Linux** 系统下编写，并利用 `CMake` 进行编译，编译后的可执行文件存放于 `build/main` 

此次 `GetDistance` 模块由 `杰锐微通 DF-100 2.8mm 90度` 摄像头来完成

~~不知道什么时候会用 `Python` 来抄一遍，但是我感觉我懒~~

---

## 2024-01-11
### 1. FEATURE 新增
#### AutoAimming : 

C++ 程序，成功根据 **标准区** 的色块获得 **识别顺序** 和 **目标位置**

### 2. CHANGE 变更
无

### 3. FIXED 修复
无

### 4. ILLUSTRATION 说明
`AutoAimming` 在 **Linux** 系统下编写，并利用 `CMake` 进行编译，编译后的可执行文件存放于 `build/main` 

---

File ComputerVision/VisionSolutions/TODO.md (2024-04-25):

# Different Solutions for Vision Part

## - [] 最简：暴力瞄准

只对目标进行一次计算，得到所有色块的信息后，使用简单的几何关系 **计算出所需要的偏角** ，然后使用 **有线串口** 进行通信。在这个方案中，电脑只负责计算角度，传给单片机后 **不提供反馈** ，摄像头不动，激光笔动，视觉上 **不需要寻找激光笔的位置** 。

## - [] 进阶：最简动态

将摄像头和激光笔绑定在一起， **不寻找激光笔的位置** ，电脑负责计算 **目标色块距离中心的位置** ，并 **持续传输一个较小的偏转角度给单片机** ，直到目标处于摄像头中心， 然后 **将摄像头回正** ，再进行下一次计算。

> 但是在这种过程中要求不断对目标位置进行检测，对神经网络的识别流畅度以及准确度有较大的考验

## - [] 进进阶：寻找激光笔的位置

在对目标进行一次检测之后，得到所有色块的信息，然后 **寻找激光笔的位置** ，通过激光笔与目标位置的差对单片机 **持续提供一个偏转角度** ，直到激光笔进入到目标中心区域，这种情况下通过视觉进行反馈。

## - [] 高玩：寻找激光笔的位置加PID算法瞄准加2.4G无线通信

上面的动态瞄准或多或少都会出现一点小毛病，只有通过PID算法才能更加精确地调控激光笔在不同位置应该偏转的角度。而无限通信对比有线通信的优势则在于，不用连很长的线到单片机上，对传输过程中产生的噪点和损失的包容性比较大，毕竟本来线就接触不良:(

# Some Knowledges Required

## 串口通信

电脑通过串口对单片机进行收发信息

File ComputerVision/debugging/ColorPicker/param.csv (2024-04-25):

purple,
179, 56, 117		179, 56, 104
13, 25, 45			0, 15, 50
179, 99, 123
140, 0, 31
shift + bila -> add -> erode -> findcontours
blue_l
103, 55, 227		109, 59, 173
65, 3, 13966		66, 0, 141
109, 83, 213
57, 9, 148
shift + bila -> add -> erode -> findcontours
orange
18, 212, 255		18, 219, 189
0, 162, 129			0, 165, 151
shift + bila -> add -> erode -> findcontours
pink
179, 194, 209		179, 191, 193
133, 73, 154		133, 77, 153
179, 128, 225
144, 51, 144
shift + bila -> add -> erode -> findcontours
green
87, 193, 156		82, 172, 134
53, 66, 90			41, 80, 96
79, 178, 194
43, 92, 115
shift + bila -> add -> erode -> findcontours
red
179, 191, 166		179, 209, 185
76, 60, 108			148, 125, 86
179, 255, 199
151, 121, 100
shift + bila -> add -> erode -> findcontours
yellow_d
29, 188, 269		26, 191, 181
14, 142, 151		17, 140, 154
22, 202, 188
15, 140, 139
shift + bila -> add -> erode -> findcontours
blue_d
127, 218, 119		129, 211, 131
91, 51, 20			94, 58, 51
122, 227, 136
91, 95, 71
shift + bila -> add -> erode -> findcontours
yellow_l
27, 179, 184		39, 176, 198
26, 121, 149		27, 138, 146
39, 148, 211
25, 106, 174
shift + bila -> add -> erode -> findcontours
black
29, 89, 80
19, 50, 54
45, 170, 90
9, 16, 5
shift + bila -> add -> erode -> findcontours

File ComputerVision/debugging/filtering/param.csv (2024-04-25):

bilateral_color | 32
bilateral_space | 23
d | 0
shift_space | 25
shift_color | 12
add
bila | 0.5
shift | 0.5
addon | 10
// bilateral_color | 36
// bilateral_space | 29
// d | 0
//
// shift_space | 31
// shift_color | 12

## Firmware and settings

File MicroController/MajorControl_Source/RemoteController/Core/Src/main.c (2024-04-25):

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
/* Includes ------------------------------------------------------------------*/
#include "main.h"
#include "adc.h"
#include "dma.h"
#include "i2c.h"
#include "spi.h"
#include "tim.h"
#include "gpio.h"

/* USER CODE BEGIN Includes */
#include "nrf24.h"
#include "oled.h"
#include "menucontrol.h"
/* USER CODE END Includes */

/* USER CODE BEGIN PTD */

unsigned char Menu_Level = 1;
unsigned char SaveData_Should_Cpy;
unsigned char Focus_Line;
unsigned char Up_Limit = 1;
unsigned char Down_Limit = 4;
uint32_t delay_250ms = 3127 * 250;
uint32_t delay_1s = 3127 * 1000;

/* USER CODE END PTD */


/* USER CODE BEGIN PV */
unsigned char Menu_State = 0x00;
unsigned char Roller_UD_Control_State = 0;
unsigned char Trans_State = 0;
unsigned char Shovel_Manual_State = 0;
unsigned char Detect_Mode_State = 0;
unsigned char Platform_Mode_State = 0;
unsigned char Boost_State = 0;
unsigned char Key_OK = 1;

void HAL_GPIO_EXTI_Callback(uint16_t GPIO_Pin)
{
    UNUSED(GPIO_Pin);
    if (Key_OK == 1)
    {


        if (GPIO_Pin == KEY3_Pin)
        {
            Menu_State = 0x05;
        }
        if (GPIO_Pin == KEY2_Pin)
        {
            Menu_State = 0x04;
        }
        if (GPIO_Pin == KEY5_Pin) // StepOut
        {
            if (Menu_Level != 1)
            {
                OLED_Clear();
                Menu_Level = 1;
                SaveData_Should_Cpy = 1;
                OLED_ShowString(1, 1, "Roller&Boost");
                OLED_ShowString(2, 1, "Trans");
                OLED_ShowString(3, 1, "Sholve");
                OLED_ShowString(4, 1, "Camera&Platform");
                Control_Init();
                Up_Limit = 1;
                Down_Limit = 4;
                if (Shovel_Manual_State == 1)
                {
                    Menu_State = 0x19;
                    Shovel_Manual_State = 0;
                } else if (Detect_Mode_State == 1)
                {
                    Menu_State = 0x20;
                    Detect_Mode_State = 0;
                } else if (Platform_Mode_State == 1)
                {
                    Menu_State = 0x2C;
                    Platform_Mode_State = 0;
                } else if (Roller_UD_Control_State == 1)
                {
                    Menu_State = 0x34;
                    Roller_UD_Control_State = 0;
                } else if(Boost_State == 1)
                {
                    Menu_State = 0x38;
                    Boost_State = 0;
                }
            }
            if (Menu_State == 1)
            {

            }
        }
        if (GPIO_Pin == KEY4_Pin) // StepIn
        {
            if (Menu_Level == 1)
            {
                switch (Focus_Line)
                {
                    case 1:
                    {
                        OLED_Clear();
                        Menu_Level = 2;
                        SaveData_Should_Cpy = 1;
                        OLED_ShowString(1, 1, "*Roller*");
                        OLED_ShowString(2, 1, "Up&Down");
                        OLED_ShowString(3,1,"Boost_Mode");
                        Up_Limit = 2;
                        Down_Limit = 3;
                        Menu_Sec_Init();
                        break;
                    }
                    case 2:
                    {
                        OLED_Clear();
                        Menu_Level = 3;
                        SaveData_Should_Cpy = 1;
                        OLED_ShowString(1, 1, "*Trans*");
                        OLED_ShowString(2, 1, "Start or Stop");
                        OLED_ShowString(3, 1, "UnFold");
                        OLED_ShowString(4, 1, "Fold");
                        Up_Limit = 2;
                        Down_Limit = 4;
                        Menu_Sec_Init();
                        break;
                    }
                    case 3:
                    {
                        OLED_Clear();
                        Menu_Level = 4;
                        SaveData_Should_Cpy = 1;
                        OLED_ShowString(1, 1, "*Sholve*");
                        OLED_ShowString(2, 1, "Manual*None*");
                        OLED_ShowString(3, 1, "Auto Once");
                        OLED_ShowString(4, 1, "Manual Switch");
                        Up_Limit = 3;
                        Down_Limit = 4;
                        Menu_Sec_Init();
                        break;
                    }
                    case 4:
                    {
                        OLED_Clear();
                        Menu_Level = 5;
                        SaveData_Should_Cpy = 1;
                        OLED_ShowString(1, 1, "*Camera*");
                        OLED_ShowString(3, 1, "Detect Mode");
                        OLED_ShowString(4, 1, "Platform");
                        Up_Limit = 3;
                        Down_Limit = 4;
                        Menu_Sec_Init();
                        break;
                    }
                    default:
                    {
                    }
                }
            } else if (Menu_Level == 2) //Roller
            {
                switch (Focus_Line)
                {
                    case 2:
                    {
                        if (Roller_UD_Control_State == 0)
                        {
                            Menu_State = 0x35;
                            Roller_UD_Control_State = 1;
                            OLED_ShowString(4, 1, "Controlling");
                        } else if (Roller_UD_Control_State == 1)
                        {
                            Menu_State = 0x34;
                            Roller_UD_Control_State = 0;
                            OLED_ShowString(4, 1, "           ");
                        }
                        break;
                    }
                    case 3:
                    {
                        if(Boost_State == 0)
                        {
                            Menu_State = 0x39;
                            Boost_State = 1;
                            OLED_ShowString(4,1,"Boosting");
                        } else if(Boost_State == 1)
                        {
                            Menu_State =0x38;
                            Boost_State = 0;
                            OLED_ShowString(4, 1, "           ");
                        }
                    }
                    default:
                    {
                    }
                }
            } else if (Menu_Level == 3) // Trans
            {
                switch (Focus_Line)
                {
                    case 2: // Start and Stop
                    {
                        if (Trans_State == 0)
                        {
                            Menu_State = 0x0D;
                            Trans_State = 1;
                            OLED_ShowString(1, 1, "*Trans*Running");
                        } else if (Trans_State == 1)
                        {
                            Menu_State = 0x0C;
                            Trans_State = 0;
                            OLED_ShowString(1, 1, "*Trans*       ");
                        }
                        break;
                    }
                    case 3: // Unfold
                    {
                        Menu_State = 0x11;
                        break;
                    }
                    case 4: // Fold
                    {
                        Menu_State = 0x10;
                        break;
                    }
                    default:
                    {
                    }
                }
            } else if (Menu_Level == 4)
            {
                switch (Focus_Line)
                {
                    case 3:
                    {
                        Menu_State = 0x15;
                        break;
                    }
                    case 4:
                    {
                        if (Shovel_Manual_State == 0)
                        {
                            Menu_State = 0x18;
                            OLED_ShowString(2, 1, "Manual*ON*    ");
                            Shovel_Manual_State = 1;
                        } else if (Shovel_Manual_State == 1)
                        {
                            Menu_State = 0x19;
                            OLED_ShowString(2, 1, "Manual*OFF* ");
                            Shovel_Manual_State = 0;
                        }
                    }
                    default:
                    {
                    }
                }
            } else if (Menu_Level == 5)
            {
                switch (Focus_Line)
                {
                    case 3:
                    {
                        if (Detect_Mode_State == 0)
                        {
                            Menu_State = 0x21;
                            OLED_ShowString(2, 1, "Detecting");
                            Detect_Mode_State = 1;
                            break;
                        } else if (Detect_Mode_State == 1)
                        {
                            Menu_State = 0x20;
                            OLED_ShowString(2, 1, "                ");
                            Detect_Mode_State = 0;
                        }
                        break;
                    }
                    case 4:
                    {
                        if (Platform_Mode_State == 0)
                        {
                            Menu_State = 0x2D;
                            OLED_ShowString(2, 1, "Platforming");
                            Platform_Mode_State = 1;
                        } else if (Platform_Mode_State == 1)
                        {
                            Menu_State = 0x2C;
                            OLED_ShowString(2, 1, "              ");
                            Platform_Mode_State = 0;
                        }
                        break;
                    }
                    default:
                    {
                    }
                }

            }
        }
        Key_OK = 0;
        HAL_TIM_Base_Start_IT(&htim4);
    }
}

void HAL_TIM_PeriodElapsedCallback(TIM_HandleTypeDef *htim)
{
    Key_OK = 1;
    HAL_TIM_Base_Stop(&htim4);
}
/* USER CODE END PV */

void SystemClock_Config(void);
/* USER CODE BEGIN 0 */
unsigned char txbuf[32] = {0};

void ADC_To_Txbuf(uint8_t headnum, uint8_t value)
{
    txbuf[headnum] = value;
}
/* USER CODE END 0 */

/**
  * @brief  The application entry point.
  * @retval int
  */
int main(void)
{
  /* MCU Configuration--------------------------------------------------------*/

  /* Reset of all peripherals, Initializes the Flash interface and the Systick. */
  HAL_Init();

  /* Configure the system clock */
  SystemClock_Config();

  /* Initialize all configured peripherals */
  MX_GPIO_Init();
  MX_DMA_Init();
  MX_SPI1_Init();
  MX_ADC1_Init();
  MX_I2C1_Init();
  MX_TIM4_Init();
  /* USER CODE BEGIN 2 */
    uint16_t ADC_Value[4];
    unsigned char i;
    unsigned char LR_MenuControl = 1;
    HAL_ADC_Init(&hadc1);
    NRF_Init();
    OLED_Init();
    HAL_ADCEx_Calibration_Start(&hadc1);
    HAL_Delay(20);
    NRF_Check();
    NRF_TX_Mode();
    HAL_ADC_Start(&hadc1);
    OLED_ShowString(1, 1, "Roller&Boost");
    OLED_ShowString(2, 1, "Trans");
    OLED_ShowString(3, 1, "Sholve");
    OLED_ShowString(4, 1, "Camera&Platform");
    Control_Init();
    HAL_GPIO_WritePin(LED0_GPIO_Port, LED0_Pin, GPIO_PIN_SET);
  /* USER CODE END 2 */

  /* Infinite loop */
  /* USER CODE BEGIN WHILE */
    while (1)
    {
        HAL_ADC_PollForConversion(&hadc1, 8);
        if (HAL_IS_BIT_SET(HAL_ADC_GetState(&hadc1), HAL_ADC_STATE_REG_EOC)) //Get ADC
        {
            HAL_ADC_Start_DMA(&hadc1, (uint32_t *) ADC_Value, sizeof(ADC_Value) / sizeof(ADC_Value[0]));
        }

        for (i = 0; i < 4; i++) // Send ADC Value to ZET6
        {
            ADC_To_Txbuf(i, (unsigned char) (ADC_Value[i] / 256));
        }
        txbuf[31] = Menu_State;
        if (NRF_TX_Packet(txbuf) == 0x20) //Send, and if Received ACK
        {
            Menu_State = 0;
        }
        HAL_Delay(20);

//        Menu Control
        if (Shovel_Manual_State == 0 && Platform_Mode_State == 0 && Roller_UD_Control_State == 0 && Boost_State == 0)
        {
            if (LR_MenuControl == 1)
            {
                if (ADC_Value[2] > 3000)
                {
                    Control_Up();
                    while (delay_250ms--);
                    delay_250ms = 3127 * 250;
                }
                if (ADC_Value[2] < 300)
                {
                    Control_Down();
                    while (delay_250ms--);
                    delay_250ms = 3127 * 250;
                }
            }
        }
    /* USER CODE END WHILE */

    /* USER CODE BEGIN 3 */
    }
  /* USER CODE END 3 */
}

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


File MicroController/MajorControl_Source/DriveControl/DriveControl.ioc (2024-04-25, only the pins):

Mcu.UserName=STM32F103C8Tx
PA0-WKUP.GPIO_Label=T_Rack
PA0-WKUP.Signal=S_TIM2_CH1_ETR
PA1.GPIO_Label=T_Roller
PA1.Signal=S_TIM2_CH2
PA10.GPIO_Label=T_BL
PA10.Signal=S_TIM1_CH3
PA11.GPIO_Label=T_BR
PA11.Signal=S_TIM1_CH4
PA2.Signal=USART2_TX
PA3.Signal=USART2_RX
PA5.Signal=GPIO_Output
PA6.GPIO_Label=T_S_CamTwo
PA6.Signal=S_TIM3_CH1
PA7.GPIO_Label=T_S_Roller_Rise
PA7.Signal=S_TIM3_CH2
PA8.GPIO_Label=T_FL
PA8.Signal=S_TIM1_CH1
PA9.GPIO_Label=T_FR
PA9.Signal=S_TIM1_CH2
PB0.GPIO_Label=T_S_Trans_Fold
PB0.Signal=S_TIM3_CH3
PB1.GPIO_Label=T_S_Shovel
PB1.Signal=S_TIM3_CH4
PB10.GPIO_Label=T_Trans
PB10.Signal=S_TIM2_CH3
PB11.GPIO_Label=T_S_CamOne
PB11.Signal=S_TIM2_CH4
PB6.Signal=S_TIM4_CH1
PB7.Signal=S_TIM4_CH2
PB8.Signal=S_TIM4_CH3
PB9.Signal=S_TIM4_CH4
PC14-OSC32_IN.Signal=RCC_OSC32_IN
PC15-OSC32_OUT.Signal=RCC_OSC32_OUT
PD0-OSC_IN.Signal=RCC_OSC_IN
PD1-OSC_OUT.Signal=RCC_OSC_OUT

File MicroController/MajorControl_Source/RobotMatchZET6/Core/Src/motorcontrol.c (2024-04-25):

//
// Created by DTS on 2024/3/10.
//

#include "motorcontrol.h"
#include "encode.h"
#include "usart.h"


void Car_Backward()
{
    HAL_GPIO_WritePin(MotorFL_Motivate_GPIO_Port, MotorFL_Motivate_Pin, GPIO_PIN_SET);
    HAL_GPIO_WritePin(MotorFR_Motivate_GPIO_Port, MotorFR_Motivate_Pin, GPIO_PIN_RESET);
    HAL_GPIO_WritePin(MotorBL_Motivate_GPIO_Port, MotorBL_Motivate_Pin, GPIO_PIN_SET);
    HAL_GPIO_WritePin(MotorBR_Motivate_GPIO_Port, MotorBR_Motivate_Pin, GPIO_PIN_RESET);
    HAL_GPIO_WritePin(MotorFL_Slave_GPIO_Port, MotorFL_Slave_Pin, GPIO_PIN_RESET);
    HAL_GPIO_WritePin(MotorFR_Slave_GPIO_Port, MotorFR_Slave_Pin, GPIO_PIN_SET);
    HAL_GPIO_WritePin(MotorBL_Slave_GPIO_Port, MotorBL_Slave_Pin, GPIO_PIN_RESET);
    HAL_GPIO_WritePin(MotorBR_Slave_GPIO_Port, MotorBR_Slave_Pin, GPIO_PIN_SET);

}

void Car_Forward()
{
    HAL_GPIO_WritePin(MotorFL_Motivate_GPIO_Port, MotorFL_Motivate_Pin, GPIO_PIN_RESET);
    HAL_GPIO_WritePin(MotorFR_Motivate_GPIO_Port, MotorFR_Motivate_Pin, GPIO_PIN_SET);
    HAL_GPIO_WritePin(MotorBL_Motivate_GPIO_Port, MotorBL_Motivate_Pin, GPIO_PIN_RESET);
    HAL_GPIO_WritePin(MotorBR_Motivate_GPIO_Port, MotorBR_Motivate_Pin, GPIO_PIN_SET);
    HAL_GPIO_WritePin(MotorFL_Slave_GPIO_Port, MotorFL_Slave_Pin, GPIO_PIN_SET);
    HAL_GPIO_WritePin(MotorFR_Slave_GPIO_Port, MotorFR_Slave_Pin, GPIO_PIN_RESET);
    HAL_GPIO_WritePin(MotorBL_Slave_GPIO_Port, MotorBL_Slave_Pin, GPIO_PIN_SET);
    HAL_GPIO_WritePin(MotorBR_Slave_GPIO_Port, MotorBR_Slave_Pin, GPIO_PIN_RESET);
}

void Car_Rightward()
{
    HAL_GPIO_WritePin(MotorFL_Motivate_GPIO_Port, MotorFL_Motivate_Pin, GPIO_PIN_SET);
    HAL_GPIO_WritePin(MotorFL_Slave_GPIO_Port, MotorFL_Slave_Pin, GPIO_PIN_RESET);
    HAL_GPIO_WritePin(MotorFR_Motivate_GPIO_Port, MotorFR_Motivate_Pin, GPIO_PIN_RESET);
    HAL_GPIO_WritePin(MotorFR_Slave_GPIO_Port, MotorFR_Slave_Pin, GPIO_PIN_SET);
    HAL_GPIO_WritePin(MotorBL_Motivate_GPIO_Port, MotorBL_Motivate_Pin, GPIO_PIN_RESET);
    HAL_GPIO_WritePin(MotorBL_Slave_GPIO_Port, MotorBL_Slave_Pin, GPIO_PIN_SET);
    HAL_GPIO_WritePin(MotorBR_Motivate_GPIO_Port, MotorBR_Motivate_Pin, GPIO_PIN_SET);
    HAL_GPIO_WritePin(MotorBR_Slave_GPIO_Port, MotorBR_Slave_Pin, GPIO_PIN_RESET);
}

void Car_Leftward()
{
    HAL_GPIO_WritePin(MotorFL_Motivate_GPIO_Port, MotorFL_Motivate_Pin, GPIO_PIN_RESET);
    HAL_GPIO_WritePin(MotorFL_Slave_GPIO_Port, MotorFL_Slave_Pin, GPIO_PIN_SET);
    HAL_GPIO_WritePin(MotorFR_Motivate_GPIO_Port, MotorFR_Motivate_Pin, GPIO_PIN_SET);
    HAL_GPIO_WritePin(MotorFR_Slave_GPIO_Port, MotorFR_Slave_Pin, GPIO_PIN_RESET);
    HAL_GPIO_WritePin(MotorBL_Motivate_GPIO_Port, MotorBL_Motivate_Pin, GPIO_PIN_SET);
    HAL_GPIO_WritePin(MotorBL_Slave_GPIO_Port, MotorBL_Slave_Pin, GPIO_PIN_RESET);
    HAL_GPIO_WritePin(MotorBR_Motivate_GPIO_Port, MotorBR_Motivate_Pin, GPIO_PIN_RESET);
    HAL_GPIO_WritePin(MotorBR_Slave_GPIO_Port, MotorBR_Slave_Pin, GPIO_PIN_SET);
}

void Car_Counter_Clockwise()
{
    HAL_GPIO_WritePin(MotorFL_Motivate_GPIO_Port, MotorFL_Motivate_Pin, GPIO_PIN_SET);
    HAL_GPIO_WritePin(MotorFL_Slave_GPIO_Port, MotorFL_Slave_Pin, GPIO_PIN_RESET);
    HAL_GPIO_WritePin(MotorFR_Motivate_GPIO_Port, MotorFR_Motivate_Pin, GPIO_PIN_SET);
    HAL_GPIO_WritePin(MotorFR_Slave_GPIO_Port, MotorFR_Slave_Pin, GPIO_PIN_RESET);
    HAL_GPIO_WritePin(MotorBL_Motivate_GPIO_Port, MotorBL_Motivate_Pin, GPIO_PIN_SET);
    HAL_GPIO_WritePin(MotorBL_Slave_GPIO_Port, MotorBL_Slave_Pin, GPIO_PIN_RESET);
    HAL_GPIO_WritePin(MotorBR_Motivate_GPIO_Port, MotorBR_Motivate_Pin, GPIO_PIN_SET);
    HAL_GPIO_WritePin(MotorBR_Slave_GPIO_Port, MotorBR_Slave_Pin, GPIO_PIN_RESET);
}

void Car_Clockwise()
{
    HAL_GPIO_WritePin(MotorFL_Motivate_GPIO_Port, MotorFL_Motivate_Pin, GPIO_PIN_RESET);
    HAL_GPIO_WritePin(MotorFL_Slave_GPIO_Port, MotorFL_Slave_Pin, GPIO_PIN_SET);
    HAL_GPIO_WritePin(MotorFR_Motivate_GPIO_Port, MotorFR_Motivate_Pin, GPIO_PIN_RESET);
    HAL_GPIO_WritePin(MotorFR_Slave_GPIO_Port, MotorFR_Slave_Pin, GPIO_PIN_SET);
    HAL_GPIO_WritePin(MotorBL_Motivate_GPIO_Port, MotorBL_Motivate_Pin, GPIO_PIN_RESET);
    HAL_GPIO_WritePin(MotorBL_Slave_GPIO_Port, MotorBL_Slave_Pin, GPIO_PIN_SET);
    HAL_GPIO_WritePin(MotorBR_Motivate_GPIO_Port, MotorBR_Motivate_Pin, GPIO_PIN_RESET);
    HAL_GPIO_WritePin(MotorBR_Slave_GPIO_Port, MotorBR_Slave_Pin, GPIO_PIN_SET);
}

void Car_Seize()
{
    HAL_GPIO_WritePin(MotorFL_Motivate_GPIO_Port, MotorFL_Motivate_Pin, GPIO_PIN_SET);
    HAL_GPIO_WritePin(MotorFR_Motivate_GPIO_Port, MotorFR_Motivate_Pin, GPIO_PIN_SET);
    HAL_GPIO_WritePin(MotorBL_Motivate_GPIO_Port, MotorBL_Motivate_Pin, GPIO_PIN_SET);
    HAL_GPIO_WritePin(MotorBR_Motivate_GPIO_Port, MotorBR_Motivate_Pin, GPIO_PIN_SET);
    HAL_GPIO_WritePin(MotorFL_Slave_GPIO_Port, MotorFL_Slave_Pin, GPIO_PIN_SET);
    HAL_GPIO_WritePin(MotorFR_Slave_GPIO_Port, MotorFR_Slave_Pin, GPIO_PIN_SET);
    HAL_GPIO_WritePin(MotorBL_Slave_GPIO_Port, MotorBL_Slave_Pin, GPIO_PIN_SET);
    HAL_GPIO_WritePin(MotorBR_Slave_GPIO_Port, MotorBR_Slave_Pin, GPIO_PIN_SET);
}

void Roller_Forward()
{
    HAL_GPIO_WritePin(Roller_Motivate_GPIO_Port,Roller_Motivate_Pin,GPIO_PIN_RESET);
    HAL_GPIO_WritePin(Roller_Slave_GPIO_Port,Roller_Slave_Pin,GPIO_PIN_SET);
}

void Roller_Seize()
{
    HAL_GPIO_WritePin(Roller_Motivate_GPIO_Port,Roller_Motivate_Pin,GPIO_PIN_SET);
    HAL_GPIO_WritePin(Roller_Slave_GPIO_Port,Roller_Slave_Pin,GPIO_PIN_SET);
}

void Rack_Forward()
{
    HAL_GPIO_WritePin(Rack_Motivate_GPIO_Port, Rack_Motivate_Pin, GPIO_PIN_RESET);
    HAL_GPIO_WritePin(Rack_Slave_GPIO_Port, Rack_Slave_Pin, GPIO_PIN_SET);
}

void Trans_Seize()
{
    HAL_GPIO_WritePin(Trans_Motivate_GPIO_Port,Trans_Motivate_Pin,GPIO_PIN_SET);
    HAL_GPIO_WritePin(Trans_Slave_GPIO_Port,Trans_Slave_Pin,GPIO_PIN_SET);
}

void Trans_Run()
{
    HAL_GPIO_WritePin(Trans_Motivate_GPIO_Port,Trans_Motivate_Pin,GPIO_PIN_SET);
    HAL_GPIO_WritePin(Trans_Slave_GPIO_Port,Trans_Slave_Pin,GPIO_PIN_RESET);
}

void Rack_Backward()
{
    HAL_GPIO_WritePin(Rack_Motivate_GPIO_Port, Rack_Motivate_Pin, GPIO_PIN_SET);
    HAL_GPIO_WritePin(Rack_Slave_GPIO_Port, Rack_Slave_Pin, GPIO_PIN_RESET);
}

void Rack_Seize()
{
    HAL_GPIO_WritePin(Rack_Motivate_GPIO_Port, Rack_Motivate_Pin, GPIO_PIN_SET);
    HAL_GPIO_WritePin(Rack_Slave_GPIO_Port, Rack_Slave_Pin, GPIO_PIN_SET);
}
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

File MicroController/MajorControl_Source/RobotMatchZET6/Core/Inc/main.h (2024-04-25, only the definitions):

#define BREncodeA_Pin GPIO_PIN_0
#define BREncodeA_GPIO_Port GPIOA
#define BREncodeB_Pin GPIO_PIN_1
#define BREncodeB_GPIO_Port GPIOA
#define IRQ_Pin GPIO_PIN_4
#define IRQ_GPIO_Port GPIOA
#define IRQ_EXTI_IRQn EXTI4_IRQn
#define CE_Pin GPIO_PIN_4
#define CE_GPIO_Port GPIOC
#define CSN_Pin GPIO_PIN_5
#define CSN_GPIO_Port GPIOC
#define RackEncodeA_Pin GPIO_PIN_9
#define RackEncodeA_GPIO_Port GPIOE
#define RackEncodeB_Pin GPIO_PIN_11
#define RackEncodeB_GPIO_Port GPIOE
#define BLEncodeA_Pin GPIO_PIN_12
#define BLEncodeA_GPIO_Port GPIOD
#define BLEncodeB_Pin GPIO_PIN_13
#define BLEncodeB_GPIO_Port GPIOD
#define MotorFR_Motivate_Pin GPIO_PIN_7
#define MotorFR_Motivate_GPIO_Port GPIOG
#define MotorFL_Motivate_Pin GPIO_PIN_8
#define MotorFL_Motivate_GPIO_Port GPIOG
#define MotorBL_Motivate_Pin GPIO_PIN_8
#define MotorBL_Motivate_GPIO_Port GPIOC
#define MotorBR_Motivate_Pin GPIO_PIN_9
#define MotorBR_Motivate_GPIO_Port GPIOC
#define Roller_Motivate_Pin GPIO_PIN_8
#define Roller_Motivate_GPIO_Port GPIOA
#define Trans_Motivate_Pin GPIO_PIN_9
#define Trans_Motivate_GPIO_Port GPIOA
#define Rack_Motivate_Pin GPIO_PIN_10
#define Rack_Motivate_GPIO_Port GPIOA
#define FLEncodeA_Pin GPIO_PIN_15
#define FLEncodeA_GPIO_Port GPIOA
#define Roller_Slave_Pin GPIO_PIN_12
#define Roller_Slave_GPIO_Port GPIOC
#define Trans_Slave_Pin GPIO_PIN_0
#define Trans_Slave_GPIO_Port GPIOD
#define Rack_Slave_Pin GPIO_PIN_1
#define Rack_Slave_GPIO_Port GPIOD
#define MotorFL_Slave_Pin GPIO_PIN_2
#define MotorFL_Slave_GPIO_Port GPIOD
#define MotorFR_Slave_Pin GPIO_PIN_3
#define MotorFR_Slave_GPIO_Port GPIOD
#define MotorBL_Slave_Pin GPIO_PIN_4
#define MotorBL_Slave_GPIO_Port GPIOD
#define MotorBR_Slave_Pin GPIO_PIN_5
#define MotorBR_Slave_GPIO_Port GPIOD
#define FLEncodeB_Pin GPIO_PIN_3
#define FLEncodeB_GPIO_Port GPIOB
#define FREncodeA_Pin GPIO_PIN_4
#define FREncodeA_GPIO_Port GPIOB
#define FREncodeB_Pin GPIO_PIN_5
#define FREncodeB_GPIO_Port GPIOB

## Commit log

2024-01-11 New : AutoAimming ├── build ├── CMakeLists.txt ├── getrange.md ├── imgs ├── main.cpp └── process
2024-01-18 新增： GetDistance ├── 1.jpg ├── 2.jpg ├── 3.jpg ├── build ├── CMakeLists.txt ├── main.cpp ├── mathfunc ├── process └── tool 修改： AutoAimming └── mathfunc
2024-01-21 新增： GetAngle ├── CMakeLists.txt ├── funcs │ ├── CMakeLists.txt │ ├── inc │ └── src ├── main2.cpp ├── main.cpp ├── mathfunc │ ├── CMakeLists.txt │ ├── inc │ └── src ├── Pipline.md └── process ├── CMak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
2024-01-21 新增： Calibration ├─.vscode ├─calibrate ├─imgs └─shoot 修改： GetDistance
    [param.csv]
2024-01-25 新增： MicroController: 1. SerialControl 2. SerialMCU 3. SerialPWM
2024-02-06 新增sw绘制的角码、六角联轴器
    [六角联轴器.SLDPRT, 底盘(未完善）.SLDPRT, 角码.SLDPRT]
2024-02-08 New : A developing branch of the robomatch In this commit, V1 is almost failed and V2 is under development.
    [六角联轴器.SLDPRT, 底盘(未完善）.SLDPRT, 角码.SLDPRT]
2024-02-19 上传小车底盘
    [25金属电机支架.SLDPRT, 996R舵机支架.SLDPRT, DC Motor Gearbox.SLDASM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]
2024-02-20 新建 RemoteController_nRF20L01
2024-02-20 新建 PCB
2024-02-20 手柄PCB及原理图(嘉立创EDA)
2024-02-20 删除文件 MicroController/RemoteController_nRF20L01/.keep
2024-02-20 删除文件 MicroController/RemoteController_nRF20L01/PCB/.keep
2024-02-20 新建 SourceCode
2024-02-20 删除文件 MicroController/RemoteController_nRF20L01/PCB/SourceCode
2024-02-20 新建 Mearm机械臂
2024-02-20 分批上传。第一批。
    [右臂关节.SLDPRT, 右臂基部关节.SLDPRT, 右臂舵机夹板.SLDPRT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]
2024-02-20 分批上传。第二批。
    [垫片.SLDPRT, 夹爪.SLDPRT, 夹爪驱动杆.SLDPRT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]
2024-02-20 下载该压缩包可以获得这一层文件夹的所有其他内容。
2024-02-20 New : MidTermAssessment 用于提交中期考核
2024-02-20 此次提交中期考核的全部内容
2024-02-22 新建 PID速度环控制
2024-02-22 PID速度环控制关键代码v0.4
2024-02-22 encoder,c的头文件v0.4
2024-02-23 update MicroController/PID速度环控制/encoder.c. 增加了通过USART协议与VOFA+通信功能以便于调试，优化速度锁的稳定性
2024-04-14 删除文件 MicroController/PID速度环控制
2024-04-14 删除文件 MicroController/RemoteController_nRF20L01
2024-04-25 更新了电控和视觉方面的最终代码，并更新了目录结构
    [param.csv]
2024-04-25 发布新的 release tag 2.0
2024-04-26 整理和目录结构，新增电控，机械，视觉的最终代码、零件等源文件 发布新的 release, 新 tag v2.0
2024-04-27 新增电控，机械，视觉的项目源文件，清理目录中多余的成分，整理目录结构 重新发布 release 2.0 以及 tag v2.0
    [25金属电机支架.SLDPRT, 25金属电机支架.STEP, 996R舵机支架.SLDPRT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]

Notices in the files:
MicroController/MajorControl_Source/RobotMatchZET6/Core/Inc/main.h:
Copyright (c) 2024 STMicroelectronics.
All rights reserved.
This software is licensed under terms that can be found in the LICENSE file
